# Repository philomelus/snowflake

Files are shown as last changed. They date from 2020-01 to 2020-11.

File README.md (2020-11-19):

This is a schematic and PCB layout created with Kicad 5.1 for a snowflake with RGB LED's and wireless communication.

I have not had these PCB's manufactured, as I meant this as a hobby type thing and what I ended up with cost way more than I was willing to spend (the PCB is 6 layers, and even the cheap chinese pcb manufactures wanted several $100 USD to create the smallest batch).

As a result of the above, I do not know how many mistakes I've made, or whether these will even work.  This is my first wireless PCB, and while I followed all the advice and recommendations I could find, I cannot make any claim as to how well its done.  If you use it as a basis for your own project, just keep that in mind, and understand I make no claims as to whether it will work.

At some point, I'd like to refine the actual snowflak shape, as its pretty rough (I imported from an SVG created in Inkscape).  Also, it'd be nice to have multiple possible shapes rather than just the one, as well as different sizes (the default size is about 126mm (4.9in) by 132mm (5.2in)).  For its size, there are a LOT of LED's (32 per PCB!).  Partly I wanted to be able to have plenty of light points, but it also allows the LED's to be run at lower power and provide considerable amount of light and complex color saturations, making sparkling a real possibility.

Russ Gibson / November 2020

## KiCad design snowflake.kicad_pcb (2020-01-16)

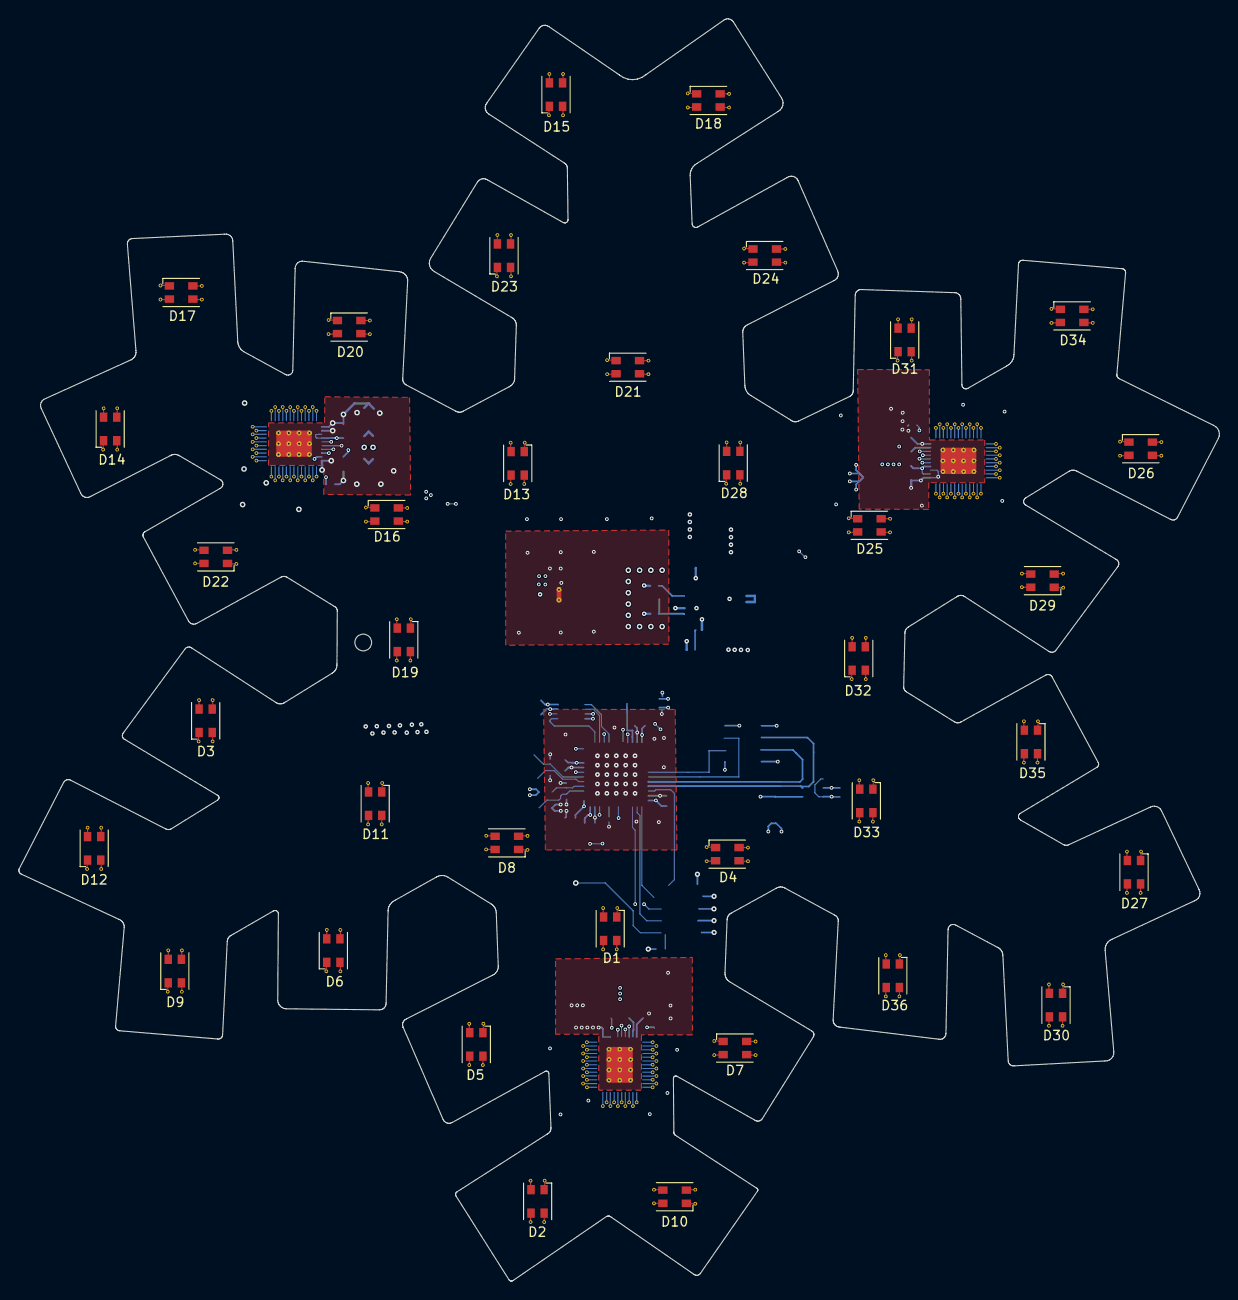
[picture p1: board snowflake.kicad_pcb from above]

Board: 6 copper layers, 127.8 x 134.4 mm, 89 parts (0 on the bottom side), 149 nets.

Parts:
C1, C2: 10uF; C_1210
C3: 47uF; C_1210
C4: 22uF; C_0603
C5: 10uF; C_0603
C6, C10, C11, C15, C16, C20, C31: 1uF; C_0603
C7, C8, C12, C13, C17, C18: 10uF; CP_Elec_3x5.3
C9, C19: 100nF; C_0402_1005Metric
C14: 150uF; C_1210_3225Metric
C21: 4.7uF; CP_Elec_3x5.3
C22, C23: 9pF; R_0201
C24, C25: 8pF; R_0201
C26, C27, C28, C29, C30: 100nF; C_0402
D1, D2, D3, D4, D5, D6, D7, D8, D9, D10, D11, D12, D13, D14, D15, D16, D17, D18, D19, D20, D21, D22, D23, D24, D25, D26, D27, D28, D29, D30, D31, D32, D33, D34, D35, D36: LED_RABG; LED-RGB-RABG-Via's
J1: 2.1mm Jack; RASM722PX
J2: ARM-JTAG-SWD-10; Pin_Header_Straight_2x05_Pitch1.27mm_SMD
J3: 2x4-1.27mm-0.05in; PinHeader_2x04_P1.27mm_Vertical_SMD_CCW
L1: 2.2uH; Inductor-Vishay-IHLP-1212BZ
R1: 40.2k; R_0402
R2: 4.42k; R_0402
R3: 10k; R_0201
R4: 1.37k; R_0402
R5, R6, R7: 3.65K; R_0402
R11: 10K; R_0201
U1: TPSM84424; TPSM84624MOLR
U2: TPS62291; WSON-6-1EP_2x2mm_P0.65mm_EP1x1.6mm_ThermalVias
U3, U4, U5: LP5036; VQFN-46-1EP_5x6mm_P0.4mm_EP2.8x3.8mm_ThermalVias_LEDVias
U6: STM32F413CHUx; QFN-48-1EP_7x7mm_P0.5mm_EP5.6x5.6mm
U7: M95512; TDFN-8-1EP_3x2mm_P0.5mm_EP1.80x1.65mm
U8: TPD3S014; SOT-23-6
Y1: 32.768K; Crystal_SMD_Epson_FC135R-2pin_3.2x1.5mm
Y2: 16Mhz; Crystal_SMD_Epson_FA20H-4pin_2.5x2.0mm

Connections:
+3V3: C5.1, C26.1, C27.1, C28.1, C29.1, C30.1, C31.1, J2.1, J3.8, L1.2, U2.3, U6.1, U6.9, U6.24, U6.36, U6.48, U7.3, U7.7, U7.8
+5V: C3.1, C4.1, C7.1, C8.1, C9.1, C10.1, C12.1, C13.1, C15.1, C17.1, C18.1, C20.1, D1.2, D2.2, D3.2, D4.2, D5.2, D6.2, D7.2, D8.2, D9.2, D10.2, D11.2, D12.2, D13.2, D14.2, D15.2, D16.2, D17.2, D18.2, D19.2, D20.2, D21.2, D22.2, D23.2, D24.2, D25.2, D26.2, D27.2, D28.2, D29.2, D30.2, D31.2, D32.2, D33.2, D34.2, D35.2, D36.2, R3.1, U1.1, U1.8, U2.2, U2.4, U2.5, U3.40, U4.39, U4.40, U5.38, U5.40, U8.1, U8.3
/+5V Supply/+12V: C1.1, C2.1, J1.3, U1.11, U1.22
/+5V Supply/AGND: R1.2, R2.2, R4.2, U1.3, U1.9, U1.23
/MCU/BOOT: R11.2, U6.44
/MCU/DBG_RX: J3.7, U6.31
/MCU/DBG_TX: J3.6, U6.30
/MCU/HSE_IN: C24.1, U6.3, Y2.1
/MCU/HSE_OUT: C25.1, U6.4, Y2.3
/MCU/LSE_IN: C22.1, U6.5, Y1.1
/MCU/LSE_OUT: C23.1, U6.6, Y1.2
/MCU/MCK-CFG: U6.15, U7.6
/MCU/MCS-CFG: U6.14, U7.1
/MCU/MISO-CFG: U6.17, U7.5
/MCU/MOSI-CFG: U6.16, U7.2
/MCU/RESET: C19.1, J2.10, U6.7
/MCU/SWCLK-TCK: J2.4, U6.37
/MCU/SWDIO-TMS: J2.2, U6.34
/MCU/TDI: J2.8, U6.38
/MCU/TDO-SWO: J2.6, U6.39
/MCU/USB-D+: J3.2, U6.33, U8.5
/MCU/USB-D-: J3.3, U6.32, U8.6
/MCU/VBUS: C14.1, J3.1, U8.4
/MCU/VCAP: C21.1, U6.22
/SCL: U3.42, U4.42, U5.42, U6.21
/SDA: U3.41, U4.41, U5.41, U6.46
/SEN-LED-1: U3.43, U6.42
/SEN-LED-2: U5.43, U6.20
/SEN-LED-3: U4.43, U6.12
GND: C1.2, C2.2, C3.2, C4.2, C5.2, C6.2, C7.2, C8.2, C9.2, C10.2, C11.2, C12.2, C13.2, C14.2, C15.2, C16.2, C17.2, C18.2, C19.2, C20.2, C21.2, C22.2, C23.2, C24.2, C25.2, C26.2, C27.2, C28.2, C29.2, C30.2, C31.2, J1.1, J2.3, J2.5, J2.7, J2.9, J3.4, J3.5, R5.2, R6.2, R7.2, R11.1, U1.12, U1.13, U1.14, U1.15, U1.18, U1.19, U1.20, U1.21, U2.6, U2.7, U3.37, U3.38, U3.39, U3.46, U3.47, U4.37, U4.38, U4.46, U4.47, U5.37, U5.39, U5.46, U5.47, U6.8, U6.23, U6.35, U6.47, U6.49, U7.4, U8.2, Y2.2, Y2.4
unnamed: C6.1, U3.45
unnamed: C11.1, U4.45
unnamed: C16.1, U5.45
unnamed: D1.1, U3.1
unnamed: D1.3, U3.3
unnamed: D1.4, U3.2
unnamed: D2.1, U3.13
unnamed: D2.3, U3.15
unnamed: D2.4, U3.14
unnamed: D3.1, U3.25
unnamed: D3.3, U3.27
unnamed: D3.4, U3.26
unnamed: D4.1, U3.4
unnamed: D4.3, U3.6
unnamed: D4.4, U3.5
unnamed: D5.1, U3.16
unnamed: D5.3, U3.18
unnamed: D5.4, U3.17
unnamed: D6.1, U3.28
unnamed: D6.3, U3.30
unnamed: D6.4, U3.29
unnamed: D7.1, U3.7
unnamed: D7.3, U3.9
unnamed: D7.4, U3.8
unnamed: D8.1, U3.19
unnamed: D8.3, U3.21
unnamed: D8.4, U3.20
unnamed: D9.1, U3.31
unnamed: D9.3, U3.33
unnamed: D9.4, U3.32
unnamed: D10.1, U3.10
unnamed: D10.3, U3.12
unnamed: D10.4, U3.11
unnamed: D11.1, U3.22
unnamed: D11.3, U3.24
unnamed: D11.4, U3.23
unnamed: D12.1, U3.34
unnamed: D12.3, U3.36
unnamed: D12.4, U3.35
unnamed: D13.1, U4.1
unnamed: D13.3, U4.3
unnamed: D13.4, U4.2
unnamed: D14.1, U4.13
unnamed: D14.3, U4.15
unnamed: D14.4, U4.14
unnamed: D15.1, U4.25
unnamed: D15.3, U4.27
unnamed: D15.4, U4.26
unnamed: D16.1, U4.4
unnamed: D16.3, U4.6
unnamed: D16.4, U4.5
unnamed: D17.1, U4.16
unnamed: D17.3, U4.18
unnamed: D17.4, U4.17
unnamed: D18.1, U4.28
unnamed: D18.3, U4.30
unnamed: D18.4, U4.29
unnamed: D19.1, U4.7
unnamed: D19.3, U4.9
unnamed: D19.4, U4.8
unnamed: D20.1, U4.19
unnamed: D20.3, U4.21
unnamed: D20.4, U4.20
unnamed: D21.1, U4.31
unnamed: D21.3, U4.33
unnamed: D21.4, U4.32
unnamed: D22.1, U4.10
unnamed: D22.3, U4.12
unnamed: D22.4, U4.11
unnamed: D23.1, U4.22
unnamed: D23.3, U4.24
unnamed: D23.4, U4.23
unnamed: D24.1, U4.34
unnamed: D24.3, U4.36
unnamed: D24.4, U4.35
unnamed: D25.1, U5.1
unnamed: D25.3, U5.3
unnamed: D25.4, U5.2
unnamed: D26.1, U5.13
unnamed: D26.3, U5.15
unnamed: D26.4, U5.14
unnamed: D27.1, U5.25
unnamed: D27.3, U5.27
unnamed: D27.4, U5.26
unnamed: D28.1, U5.4
unnamed: D28.3, U5.6
unnamed: D28.4, U5.5
unnamed: D29.1, U5.16
unnamed: D29.3, U5.18
unnamed: D29.4, U5.17
unnamed: D30.1, U5.28
unnamed: D30.3, U5.30
unnamed: D30.4, U5.29
unnamed: D31.1, U5.7
unnamed: D31.3, U5.9
unnamed: D31.4, U5.8
unnamed: D32.1, U5.19
unnamed: D32.3, U5.21
unnamed: D32.4, U5.20
unnamed: D33.1, U5.31
unnamed: D33.3, U5.33
unnamed: D33.4, U5.32
unnamed: D34.1, U5.10
unnamed: D34.3, U5.12
unnamed: D34.4, U5.11
unnamed: D35.1, U5.22
unnamed: D35.3, U5.24
unnamed: D35.4, U5.23
unnamed: D36.1, U5.34
unnamed: D36.3, U5.36
unnamed: D36.4, U5.35
unnamed: L1.1, U2.1
unnamed: R1.1, U1.24
unnamed: R2.1, U1.5
unnamed: R3.2, R4.1, U1.2
unnamed: R5.1, U3.44
unnamed: R6.1, U4.44
unnamed: R7.1, U5.44
unnamed: U1.16, U1.17

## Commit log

2020-01-12 Initial import.
    [LED.sch, MCU.sch, Power-3V3.sch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]
2020-01-12 File structure cleanup.
    [power-supply.sch, powersupply.sch, snowflake - Copy.sch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]
2020-01-16 Merged usb and debug to single 1.27mm header.
    [LED.sch, MCU.sch, snowflake.csv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]
2020-01-16 More assembly updates; Nothing major.
    [snowflake-m-bom.xlsx]
2020-11-19 Final changes. Its beedn a few months, so I do not remember exactly, but diffs show enough changes to make it worth keeping the revisions. Everything *looks* ok.
    [LED.sch, MCU.sch, Power-3V3.sch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]
2020-11-19 Removed generated BOM files (pdf, xlsx) from git.
    [snowflake-m-bom.xlsx]
2020-11-19 Removed (missed) BOM csv.
    [snowflake.csv]
